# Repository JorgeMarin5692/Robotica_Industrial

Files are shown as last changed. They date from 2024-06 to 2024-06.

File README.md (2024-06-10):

# Proyecto Robotica 

Este repositorio GitHub contiene los documentos y archivos necesarios para construir un robot de 5 grados de libertad (5DOF). El robot está diseñado para ser una plataforma versátil para el aprendizaje y la experimentación en robótica. Se puede utilizar para una amplia gama de tareas, incluyendo:

- Manipulación de objetos: El robot puede agarrar y mover objetos de diferentes formas y tamaños.
- Brazo robótico: El robot se puede utilizar como un brazo robótico para realizar tareas más complejas.

# Diseño 3D
El inicio del proyecto de creación de un brazo robótico por parte de estudiantes estuvo marcado por la crucial etapa del diseño 3D, utilizando la herramienta Solidworks como piedra angular para el éxito del mismo. Solidworks, un software de CAD (Diseño Asistido por Computadora) de gran potencia y versatilidad, permitió a los estudiantes plasmar sus ideas en modelos digitales precisos y detallados.

Esta etapa inicial fue de vital importancia, ya que sentó las bases para el posterior desarrollo físico del brazo robótico. Mediante Solidworks, los estudiantes pudieron crear representaciones virtuales de cada componente del brazo, desde las articulaciones y eslabones hasta los elementos de sujeción y control. Esto permitió a los involucrados en el proyecto visualizar con claridad la forma, dimensiones y relaciones entre las distintas partes del robot, facilitando así la toma de decisiones técnicas acertadas.

La precisión y el detalle de los modelos 3D generados en Solidworks no solo fueron útiles para la conceptualización del diseño, sino que también sirvieron como insumo fundamental para la etapa de manufactura. Los modelos digitales pudieron exportarse en formatos compatibles con las impresoras 3D, permitiendo la fabricación precisa y eficiente de cada componente del brazo robótico. De esta manera, las ideas de los estudiantes se materializaron en piezas físicas tangibles.

WhatsApp Image 2024-06-09 at 6 02 45 PM

# Adquisición de los componentes

Tras la meticulosa etapa de diseño 3D, llegó el momento de materializar el brazo robótico mediante la adquisición de los componentes necesarios para su construcción. Con base en las especificaciones técnicas definidas durante la fase de diseño, se procedió a la compra de los siguientes elementos:

Servomotores: Se seleccionaron dos tipos de servomotores para el proyecto: los MG996R y los SG90. Los MG996R, con su mayor torque y precisión, se destinaron a las articulaciones principales del brazo, mientras que los SG90, más económicos y livianos, se emplearon en las articulaciones secundarias.

Placa Arduino Uno: Esta placa microcontroladora, reconocida por su facilidad de uso y versatilidad, se convirtió en el cerebro del brazo robótico. Su capacidad de procesamiento y comunicación con los periféricos la convirtió en la opción ideal para controlar los movimientos del brazo y la interacción con los sensores.

Placa PCA9685: Para ampliar la capacidad de control de servomotores del Arduino Uno, se incorporó la placa PCA9685. Esta placa de expansión permitió conectar y controlar hasta 16 servomotores adicionales, lo que resultó fundamental para la compleja estructura articulada del brazo robótico.

Jumpers: Estos cables de conexión flexibles sirvieron para establecer las conexiones eléctricas entre la placa Arduino Uno, la placa PCA9685, los servomotores y los sensores. Su practicidad y facilidad de uso agilizaron el proceso de ensamblaje y configuración del sistema.

Fuente de voltaje: Para alimentar de forma estable a todos los componentes electrónicos del brazo robótico, se adquirió una fuente de voltaje de corriente continua con la capacidad y el voltaje adecuados. Esto garantizó el correcto funcionamiento de los servomotores, la placa Arduino Uno y la placa PCA9685.

Filamento PLA: Para la impresión 3D de las piezas diseñadas en Solidworks, se utilizó filamento PLA (ácido poliláctico). Este material biodegradable, de alta calidad y fácil impresión, fue la elección ideal para la fabricación de las estructuras livianas y resistentes del brazo robótico.

Tornillería: Para asegurar la fijación precisa y robusta de las piezas impresas en 3D y los componentes electrónicos, se adquirió un surtido de tornillos, tuercas y arandelas de diferentes tamaños y materiales. La selección cuidadosa de la tornillería garantizó la estabilidad y durabilidad del brazo robótico.

WhatsApp Image 2024-06-09 at 6 00 48 PM

# Entorno de simulación 

Tras haber desarrollado el brazo robótico físico y su sistema de control mediante programación automática, el siguiente paso crucial en el proyecto es la creación de un entorno de simulación virtual. Este entorno permitirá probar, validar y optimizar el funcionamiento del brazo robótico en un ambiente controlado antes de su implementación en el mundo real.

Para la creación del entorno de simulación, se utilizará la combinación de dos potentes herramientas:

- ROS2 (Robot Operating System 2): Un marco de software de código abierto ampliamente utilizado en robótica para la comunicación entre diferentes nodos y la ejecución de tareas de forma distribuida.

- MoveIt: Un conjunto de herramientas de software para la planificación de movimiento y la manipulación robótica, integrado en el ecosistema ROS2. MoveIt proporciona algoritmos avanzados para generar trayectorias seguras y eficientes para el brazo robótico, considerando las limitaciones físicas y las restricciones del entorno.

Pasos para la creación del entorno de simulación:

- Instalación de ROS2 y MoveIt: Se instalará ROS2 y MoveIt en el sistema Ubuntu siguiendo las instrucciones oficiales de instalación.

- Modelado del brazo robótico: Se creará un modelo 3D preciso del brazo robótico utilizando herramientas de modelado 3D como es Solidworks. El modelo debe incluir todas las articulaciones, dimensiones y propiedades físicas del brazo real.

- Integración del modelo en ROS2: Se integrará el modelo 3D del brazo robótico en el entorno de simulación ROS2 utilizando herramientas como RViz. Esto permitirá visualizar el brazo robótico en el entorno virtual y controlar sus movimientos mediante comandos ROS2.

- Configuración de MoveIt: Se configurará MoveIt para que funcione con el modelo del brazo robótico y el entorno de simulación. Esto implica definir las articulaciones, las propiedades físicas y los límites de movimiento del brazo, así como los parámetros de planificación de movimiento.

- Pruebas y validación: Se realizarán pruebas exhaustivas para verificar el correcto funcionamiento del entorno de simulación, la precisión del modelo del brazo robótico y la eficacia de los algoritmos de planificación de movimiento de MoveIt.

Beneficios del entorno de simulación:

- Validación de movimientos: El entorno de simulación permite probar y validar diferentes movimientos del brazo robótico sin necesidad de riesgo para el hardware real.

- Optimización de la programación: Se puede optimizar la programación del brazo robótico en el entorno de simulación antes de implementarla en el sistema físico.

- Detección de errores: El entorno de simulación facilita la detección de errores en la programación o en el modelo del brazo robótico antes de que causen problemas en el sistema real.

- Entrenamiento de algoritmos: El entorno de simulación puede utilizarse para entrenar y optimizar algoritmos de control o de planificación de movimiento para el brazo robótico.

- Pruebas en diferentes entornos: Se pueden realizar pruebas en diferentes entornos virtuales para evaluar el comportamiento del brazo robótico en diversas situaciones y condiciones.
  
WhatsApp Image 2024-06-09 at 7 09 23 PM

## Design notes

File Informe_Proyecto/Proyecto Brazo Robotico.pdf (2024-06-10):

# Brazo robotico ´

### Mateo Mendoza Vera mmendoz80080@universidadean.edu.co Jorge Andres Mar ´ ín jmarina75692@universidadean.edu.co Guillermo Esteban Marquez ´ gmarque75991@universidadean.edu.co Camilo Andres Avilan Payares cavilan11027@universidadean.edu.co

### Universidad EAN Facultad de Ingeniería

Diseno Mecatr ˜ | onica ´

### Bogotá

2024

1

## Resumen

Este documento se enfoca en la creacion de un brazo rob ´ | otico articulado, ´
disenado principalmente para exposiciones acad ˜ | emicas, en este caso para la ´
unidad de estudio Diseno mecatronico. Aborda los problemas de eficiencia y ˜ seguridad presentes en disenos anteriores, con el objetivo de mejorar estos as- ˜ pectos. La metodología implementada abarca desde el diseno inicial hasta el ˜ ensamblaje final, haciendo uso de Trello como herramienta para el seguimiento
del proyecto. Se destaca por obtener como resultado un brazo robotico r ´ | api- ´
do, confiable y seguro, adecuado para demostraciones academicas a peque ´ | nã
escala.

## Introducción

En este proyecto se desarrolla un brazo robotico de 4 grados de libertad ´ (DoF) utilizando servomotores, con un diseno tridimensional elaborado en So- ˜ lidWorks y controlado mediante una tarjeta Arduino. La programacion del bra- ´ zo robotico se realiza en ROS2 (Robot Operating System 2), un marco de trabajo ´
robusto y flexible que permite la simulacion y control de sistemas rob ´ | oticos. ´

## Objetivo General

Disenar, construir y programar un brazo rob ˜ | otico que sea capaz de realizar ´
tareas de manipulacion y agarre de objetos en un entorno simulado y real. ´ Para lograr esto, se emplean herramientas de diseno asistido por computadora ˜ (CAD) como solidworks para modelar cada componente del brazo, servomotores para el movimiento preciso de las articulaciones, y una tarjeta Arduino para
el control y la comunicacion con el software de ROS2. La simulaci ´ | on en ROS2 ´
permite probar y validar los algoritmos de control y las trayectorias del brazo antes de implementarlos en el hardware real. Esta metodología reduce el riesgo
de errores y danos en el prototipo f ˜ | ísico, ademas de facilitar la optimizaci ´ | on de ´
los parametros del sistema. ´

## Objetivos Específicos

Crear un modelo detallado del brazo robotico en SolidWorks, incluyendo ´ eslabones, juntas y el mecanismo de la pinza.

Desarrollar y programar los algoritmos de cinematica directa e inversa ´ para controlar el movimiento del brazo.

Implementar el modelo del brazo en un entorno de simulacion utilizando ´ ROS2, y probar las capacidades de manipulacion y agarre. ´

2

Imprimir en 3D las piezas del brazo robotico, ensamblar el hardware y ´ conectar los servomotores a la tarjeta Arduino.

Programar la tarjeta Arduino para recibir comandos desde ROS2 y controlar los servomotores, y realizar pruebas funcionales para asegurar que el brazo opere segun lo previsto. ´

## 1. Estado del Arte

Los brazos roboticos, son dispositivos programables que imitan el movi- ´ miento y la funcion de un brazo humano. Se componen de una serie de eslabo- ´ nes conectados por articulaciones que les permiten realizar una amplia gama de movimientos, incluyendo:

Flexion´ /extension: Movimiento de un eslab ´ | on hacia adentro o hacia afuera ´
de una articulacion. ´
Abduccion´ /aduccion: Movimiento de un eslab ´ | on alej ´ | andose o acerc ´ | ando- ´
se al cuerpo del robot.
Rotacion: Movimiento de un eslab ´ | on alrededor de su eje longitudinal. ´
Los brazos roboticos son muy vers ´ | atiles en cuanto a sus funciones y las ´
aplicaciones que este puede realizar. En muchas empresas implementan estos
brazos roboticos tambi ´ | en por la precisi ´ | on que pueden llegar a tener en ciertas ´
tareas; aquí se presentan algunas aplicaciones de los brazos roboticos: ´

Manufactura: Puede ser el ensamblaje de productos, soldadura, pintura, manipulacion de materiales. ´

Logística: Desde el almacenamiento y recuperacion de productos, empa- ´ quetado, paletizado.

Medicina: Cirugía robotica, rehabilitaci ´ | on f ´ ísica, asistencia a personas con
discapacidades.

Agricultura: Cosecha de frutas y verduras, ordeno de vacas, control de ˜ plagas.

Exploracion espacial: Mantenimiento de sat ´ | elites, exploraci ´ | on de plane- ´
tas, recoleccion de muestras. ´

### 1.1. Componentes de un brazo robótico

Los principales componentes de un brazo robotico convencional son: ´

Eslabones: Segmentos rígidos que forman la estructura del brazo.

Articulaciones: Uniones entre eslabones que permiten el movimiento.

3

Actuadores: Motores que proporcionan la fuerza para mover las articulaciones.

Sensores: Dispositivos que recopilan informacion sobre el entorno del ´ brazo.

Controlador: Un sistema informatico que procesa las se ´ | nales de los sen- ˜
sores y envía comandos a los actuadores.

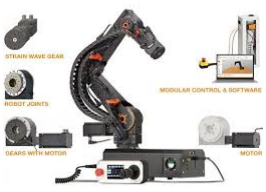
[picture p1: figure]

Figura 1: Componentes de un Brazo Robotico

Aunque segun la complejidad del brazo rob ´ | | | otico se podr ´ | ían necesitar otros
materiales o con otro tipo de características específicas.

### 1.2. Tipos de brazos robóticos

Existen gran variedad de brazos roboticos seg ´ | un sus caracter ´ | ísticas, clasi-
ficados segun su dise ´ | no, cinem ˜ | atica y aplicaci ´ | on. Algunos de los tipos m ´ | as´
comunes son:
Brazos roboticos articulados: El tipo m ´ | as com ´ | un, con una serie de eslabo- ´
nes conectados por articulaciones rotativas.

Brazos roboticos cartesianos: Se mueven en tres direcciones ortogonales ´ (X, Y, Z) mediante actuadores lineales.

Brazos roboticos de brazo scara: Un tipo de brazo cartesiano con mayor ´ alcance y flexibilidad.

Brazos roboticos colaborativos (cobots): Dise ´ | nados para trabajar de forma ˜
segura junto a humanos. (Blog, s/f)

4

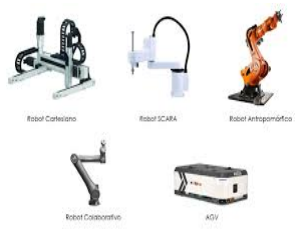
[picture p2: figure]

Figura 2: Tipos de brazos roboticos

### 1.3. Evolución de los brazos Robóticos

Aquí se exponen algunas de las tecnologías clave que estan impulsando el ´ desarrollo de brazos roboticos: ´

Inteligencia artificial (IA): La IA se utiliza para mejorar la precision, la ´ destreza y la autonomía de los brazos roboticos. ´

Robotica sensorial: Los sensores cada vez m ´ | as sofisticados proporcionan ´
a los brazos roboticos una mejor comprensi ´ | on de su entorno. ´
Materiales avanzados: Los materiales mas ligeros y resistentes est ´ | an per- ´
mitiendo construir brazos roboticos m ´ | as eficientes y duraderos. ´
Impresion 3D: La impresi ´ | on 3D est ´ | a facilitando la creaci ´ | on de brazos ´
roboticos personalizados y complejos. ´

### 1.4. Aplicaciones futuras de los brazos robóticos

Se espera que los brazos roboticos tengan un impacto cada vez mayor en ´
nuestras vidas en los proximos a ´ | nos. Algunas de las aplicaciones potenciales ˜
incluyen:
Cuidado en el hogar: Los brazos roboticos podr ´ | ían ayudar a las personas
mayores y discapacitadas con tareas como cocinar, vestirse y banarse. ˜
Educacion: Los brazos rob ´ | oticos podr ´ | | ían utilizarse para ensenar a los ˜
estudiantes sobre robotica, ingenier ´ | | ía y otras materias.
Entretenimiento: Los brazos roboticos podr ´ | ían utilizarse para crear expe-
riencias de entretenimiento mas inmersivas. ´

5

Construccion: Los brazos rob ´ | oticos podr ´ | ían utilizarse para construir es-
tructuras mas seguras y eficientes. ´

### 1.5. Cinematica

(Inversa, s/f,pg 4. Estudia el movimiento del robot con respecto a un sistema de referencia sin considerar las fuerzas que intervienen. Estudia, ademas, las ´ relaciones entre las velocidades del movimiento de las articulaciones y las del extremo.)

### 1.5.1. Cinematica Inversa

(Inversa, s/f, pg 5. Consiste en determinar la posicion y orientaci ´ | on del ´
extremo final del robot, con respecto a un sistema de referencia, conocidos
los valores de las articulaciones (angulos) y los par ´ | ametros geom ´ | etricos de los ´
elementos del robot.)

### 1.5.2. Cinematica directa

(Inversa, s/f, pg 5. Consiste en determinar la posicion y orientaci ´ | on del ´
extremo final del robot, con respecto a un sistema de referencia, conocidos
los valores de las articulaciones (angulos) y los par ´ | ametros geom ´ | etricos de los ´
elementos del robot.)

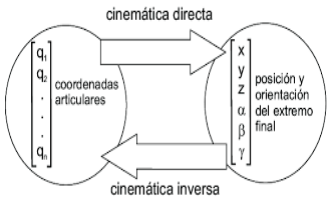
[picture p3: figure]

Figura 3: Comparacion cinematica inversa y directa

### 1.6. ROS2

O Robot Operating System 2, es la version m ´ as reciente y avanzada del ´ Sistema Operativo de Robots (ROS). Es una plataforma de desarrollo de codigo ´
abierto disenada para facilitar la creaci ˜ | on y operaci ´ | on de sistemas rob ´ | oticos ´
complejos. A diferencia de su predecesor, ROS, ROS2 esta dise ´ | nado para ser ˜

6

mas escalable, modular, robusto y adecuado para una variedad m ´ | as amplia de ´
aplicaciones y entornos.

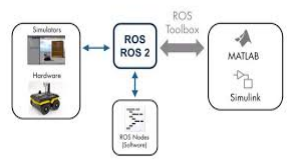
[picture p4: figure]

Figura 4: Apliccaciones ROS2

## 2. Metodología

Para el desarrollo de un brazo robotico se toma el siguiente procedimiento ´ general, aunque este procedimiento tendra que dividirse en etapas: ´

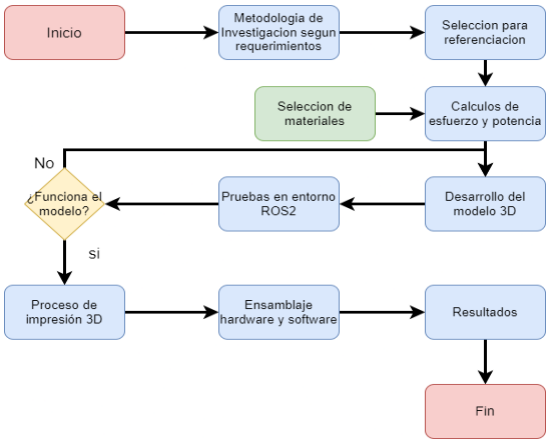
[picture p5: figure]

Figura 5: Ciclo de metodologia

7

A partir del estado del arte se pudo obtener un marco referencial respecto a proyectos con características similares tanto en el software y el hardware. Para
este caso, el tipo de brazo robotico a realizar es un brazo rob ´ | otico articulado el ´
cual es rapido, confiable y seguro; a una escala peque ´ | na, ideal para exposici ˜ | on´
en terminos acad ´ | emicos. La estructura, es decir, el hardware, est ´ | a basado en ´
este video: ([@FABRIcreator]., 2024). Para terminos de seguimiento de avances ´ se utiliza la plataforma de trello para buscar eficiencia en el proceso de cada uno de los participantes; este proyecto se divide en tres etapas principales: Diseno, ˜ definicion de presupuesto y ensamble ´

### 2.1. Dise ño

Teniendo en primera instancia el diseno se procede a hacer c ˜ | alculos genera- ´
les de los eslabones y el ensamble en general para así tener una idea de variables a tener en cuenta como torque necesario de los servomotores, esfuerzo, entre otras para asi hacer la respectiva seleccion de materiales. Para hacer calculos generales se necesita una densidad especifica para determinar la masa por cada cm3, por esto se acude a la siguiente tabla tomada de (Fonseca, s/f, p.26).

Cuadro 1: Comparacion de materiales ´
Características / Material Aluminio | Acero | Polímeros (PLA) Titanio
Densidad | 7 | 5 | 9 | 3
Transformacion | 8 | 8 | 3 | 3 ´
Acceso | 7 | 7 | 7 | 2
Restricciones intrínsecas | 7 | 8 | 5 | 9
Ensamblaje | 8 | 6 | 6 | 7
Resistencia mecanica | 7 | 8 | 6 | 10 ´
Compactibilidad | 5 | 2 | 3 | 10
Precio | 6 | 6 | 5 | 1
Total | 55 | 50 | 51 | 45
Se toma la decision de elegir la secci ´ | on de pol ´ | ímeros, específicamente el
PLA (Poliacido L ´ | actico), ya que como su objetivo es demostrarse en ´ | ambitos ´
academicos, su precio es el mas ascequible, esto sin desmeritar las propiedades ´ y ventajas que ofrece este material. Este material cuenta con una densidad de 1,24 g/cm3. Por consiguiente es necesario un procedimiento grafico para hacer la resolucion de calculos, es por eso que se disena un diagrama de cuerpo libre ˜ tentativo para asi tener una guia procedimental A continuacion se presenta una tabla con cada una de las piezas que componen al brazo robotico y sus caracteristicas para terminos de calculos.
Ahora se procede a hacer los calculos generales

8

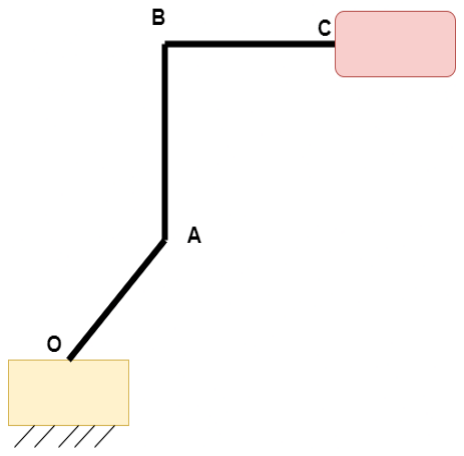
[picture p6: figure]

Figura 6: Diagrama de cuerpo Libre

Cuadro 2: Pesos y medidas de los componentes del brazo robotico ´
Componente | Peso | Medida
Servomotor MG996R | 55 gramos | -
Servomotor SG90 | 9 gramos | -
Seccion OA | 85 gramos | 4,05 cm ´
Seccion AB | 68,3 gramos | 12,0 cm ´
Seccion BC | 62,2 gramos | 9 cm ´
Sistema Garra | 32 gramos | 6,3 cm

### 2.1.1. Cálculos

Parámetros

L1 = 0,0405 m, | m1 = 0,855 kg | (1)
L2 = 0,12 m, | m2 = 0,682 kg | (2)
L3 = 0,09 m, | m3 = 0,62 kg | (3)
L4 = 0,063 m, | m4 = 0,57 kg | (4)
Carga tentativa = 0,5 kg | | (5)

Peso de cada segmento

Fg1 = 0,855 kg · 9,81 m/s | 2 = 8,38355 N | (6)
Fg2 = 0,682 kg · 9,81 m/s | 2 = 6,68842 N | (7)
Fg3 = 0,62 kg · 9,81 m/s | 2 = 6,0822 N | (8)
Fg4 = 0,57 kg · 9,81 m/s | 2 = 5,5917 N | (9)
Fc = 0,5 kg · 9,81 m/s | 2 = 4,905 N | (10)

9

Distancia desde articulación a centro de masa: Se supone las articulaciones como barras, por lo tanto, su centro de masa va a ser la mitad de su medida

dcm1 =

L1
2
= 0,02025 m | (11)

dcm2 =

L2
2
= 0,06 m | (12)

dcm3 =

L3
2
= 0,045 m | (13)

dcm4 =

L4
2
= 0,0315 m | (14)

Calculo de momento para cada articulacion

Articulacion 4 (debido al segmento 4 y la carga) ´

M4 = Fg4 · dcm4 = 5,5917 · 0,0315 = 0,17614905 Nm

Mc = Fc

- L4 = 4,905 · 0,063 = 0,309015 Nm

Mtotal4 = 0,17614905 + 0,309015 = 0,48516405 Nm

Articulacion 3 (debido al segmento 3, segmento 4 y la carga) ´

M3 = Fg3 · dcm3
= 6,0822 · 0,045
= 0,273699 Nm

Mtotal3 = M3 + (Mtotal4 + Fg4 · L3 + Fc

- (L3 + L4))
= 0,273699 + (0,48516405 + 5,5917 · 0,09 + 4,905 · (0,09 + 0,063)) = 0,273699 + (0,48516405 + 0,503253 + 0,750165)
= 0,273699 + 1,73858205
= 2,01228105 Nm

Articulacion 2 (debido al segmento 2, segmento 3, segmento 4 y la carga) ´

M2 = Fg2 · dcm2
= 6,68842 · 0,06
= 0,4013052 Nm

10

Mtotal2 = M2 + (Mtotal3 + Fg3 · L2 + Fg4 · (L2 + L3) + Fc

- (L2 + L3 + L4))
= 0,4013052 + (2,01228105 + 6,0822 · 0,12 + 5,5917 · (0,12 + 0,09) + 4,905 · (0,12 + 0,09 + 0,063))
= 0,4013052 + (2,01228105 + 0,729864 + 1,174257 + 1,339065) = 0,4013052 + 5,25546705
= 5,65677225 Nm

Articulacion 1 (debido al segmento 1, segmento 2, segmento 3, segmento ´ 4 y la carga)

M1 = Fg1 · dcm1
= 8,38355 · 0,02025
= 0,1697953875 Nm

Mtotal1 = M1 + (Mtotal2 + Fg2 · L1 + Fg3 · (L1 + L2) + Fg4 · (L1 + L2 + L3) + Fc

- (L1 + L2 + L3 + L4))
= 0,1697953875 + (5,65677225 + 6,68842 · 0,0405 + 6,0822 · (0,0405 + 0,12)
+ 5,5917 · (0,0405 + 0,12 + 0,09) + 4,905 · (0,0405 + 0,12 + 0,09 + 0,063))
= 0,1697953875 + (5,65677225 + 0,27087401 + 0,9762491 + 1,40017885 + 1,5374175) = 0,1697953875 + 9,84149171
= 10,0112871 Nm

Cinematica Directa y Inversa
Para calcular la cinematica directa, se utilizo el metodo de D-H(Denavit Hatenberg), para ver el movimiento del robot.
θj | dj | aj | αj
q1 | 40.38 | 0 | ◦ −90,0
q2 + 90◦ | 0 | 120 | 0,0 ◦
q3 | 115 | 0 | 90,0 ◦
q4 − 90◦ | 31.76 | 0 | 90,0 ◦
q5 | 0 | 0 | 0,0 ◦

Cuadro 3: Tabla de parametros de Denavit-Hartenberg ´

Gracias al programa Google Colab, y por medio de la libreria Robotic-Toolbox, se logro sacar los resultados tanto de la cinematica directa como aquellos abrebocas de la cinematica inversa, los cuales mas adelante se veran por medio de los metodos de Newthon Raphson (Jacobiano) Para lo siguiente se definieron los parametros cinematicos a trabajar por medio de tres ecuaciones de coordenadas del brazo (X,Y,Z).

11

0 | 1 | 0 | 31.76
-1 | 0 | 0 | 115
0 | 0 | 1 | -79.62
0 | 0 | 0 | 1

Cuadro 4: Matriz de Cinematica Directa ´

x = l1 cos(θ1)+l2 cos(θ1+θ2)+l3 cos(θ1+θ2+θ3)+l4 cos(θ1+θ2+θ3+θ4)+l5 cos(θ1+θ2+θ3+θ4+θ5) (15)

y = l1 sin(θ1)+l2 sin(θ1+θ2)+l3 sin(θ1+θ2+θ3)+l4 sin(θ1+θ2+θ3+θ4)+l5 sin(θ1+θ2+θ3+θ4+θ5) (16)

z = l1+l2 sin(θ2)+l3 sin(θ2+θ3)+l4 sin(θ2+θ3+θ4)+l5 sin(θ2+θ3+θ4+θ5)
(17)

Resultados
Los momentos calculados para cada articulacion son: ´
Articulacion 4: 0 ´ | ,4852 Nm
Articulacion 3: 2 ´ | ,0123 Nm
Articulacion 2: 5 ´ | ,6568 Nm
Articulacion 1: 10 ´ | ,0113 Nm

Es de aclarar que estos calculos da una idea del torque y de saber si es apropiado tener los servomotores que se postularon en un inicio, y por esto se supone que los motores MG996R y SG90 tienen la capacidad de torque.
Si bien en un principio el diseno para su respectiva impresi ˜ | on 3D de las ´
piezas que conforman el brazo robotico ya estaban listas, fue necesario realizar ´ el brazo a partir de las medidas de este mismos en solidworks, ya que para
la simulacion y obtenci ´ | on de planos para este software eran incompatibles los ´
archivos. Una vez listas las piezas y el ensamblaje se procede a hacer simula-
cion din ´ | amica en el software para la respectiva comparaci ´ | on con los c ´ | alculos ´
realizados anteriormente.
En el aspecto del software para el control del robot se disenõ un c ´ | odigo en ´
Python inicialmente para hacer la respectiva simulacion en ROS2 y as ´ | í verificar
los resultados de dicha simulacion con las posibles fallas del sistema. Una vez ´
teniendo todo el aspecto de diseno listo se procede a la cotizaci ˜ | on de materiales ´
y la realizacion de un presupuesto tentativo. ´

12

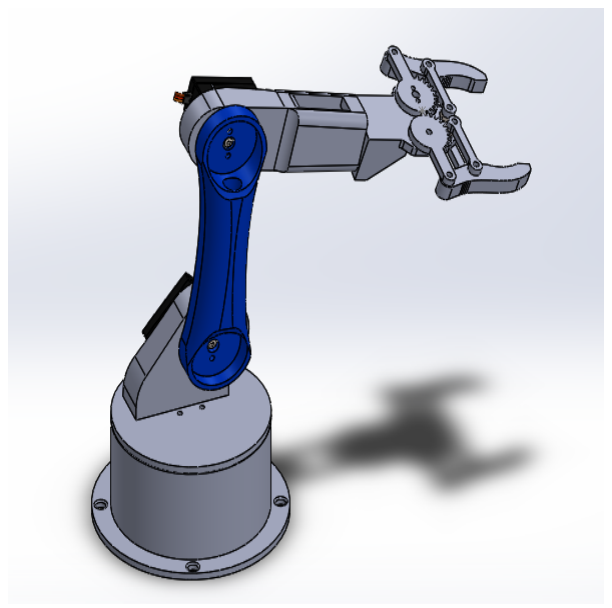
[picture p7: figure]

Figura 7: Modelo en solidworks

### 2.2. Presupuesto

Para hacer un respectivo presupuesto para la realizacion de un brazo rob ´ | oti- ´
co fue necesario revisar y analizar el estado del arte que conlleva este tipo de proyectos, incluyendo tambien un marco referencial, requisitos suministrados ´ por el tutor y algunas sugerencias de este mismo. Al hacer este proceso se pudieron implementar los siguientes materiales, a su vez se establece un posible presupuesto para implementar.

Cuadro 5: Materiales y Presupuesto
Materiales | | Cantidad | Precio Total
Filamento PLA | | 1 Kg | $80.000
Servomotor MG996R | | 2 | $60.000
Servomotor MG90S | | 1 | $18.000
Servomotor SG90 | | 1 | $13.000
Modulo PCA9685 | | 1 | $30.000
Arduino Mega | | 1 | $150.000
Tornillos m3 12mm | | 10 | $10.000
Tornillos m3 16mm | | 10 | $10.000
Miscelaneos | N ´ | /A | $20.000
| | Total: | $325.000

Es necesario tener en cuenta que los precios son tomados de internet en sitios como mercado libre, Amazon y google shopping; es por esto que, puede

13 ser que estos materiales comprados de manera física pueden variar su precio, probablemente sea menor su precio unitario.
Se tomaron los precios promedio del mercado, ya que en internet aparecen artículos con mayor y menor precio. Es por esto que se considera que el presupuesto necesario para el debido desarrollo de este proyecto sea de COP $350.000.

### 2.3. Ensamble

En esta parte del proceso es preciso indicar que se divide en dos partes, la parte de conexiones electronicas, y la parte estructural del brazo robotico. Para la parte de conexiones electronicas fue de gran ayuda el uso del modulo PCA9685, ya que reduce las conexiones al arduino y asi se puede optimizar mejor el codigo. En este caso se utilizaron exclusivamente 5 servomotores.

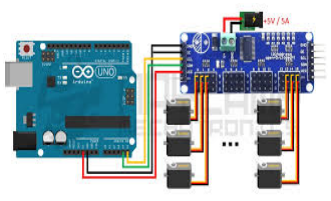
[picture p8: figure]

Figura 8: Conexiones del Brazo Robotico

Como ya se tenía el diseno, se procedi ˜ | o a someter el dise ´ | no a impresi ˜ | on´
3D para la obtencion de los eslabones y ´ | /o estructura del brazo robotico, el cual ´
con la impresora que se uso tuvo un tiempo aproximado de 18 horas para la ´ obtencion de las piezas. Teniendo las piezas y todos los elementos necesarios ´ para su construccion se procedio a ensamblar. ´
Despues se realizaron dos codigos los cuales se puede controlar el brazo de forma manual y automatica, estos se pueden encontrar en el repositorio GitHub.

## Implementación

Una vez teniendo el hardware, fue necesario acoplar el software al sistema. El software, se hizo un codigo en arduino para el respectivo control de posicion´

14

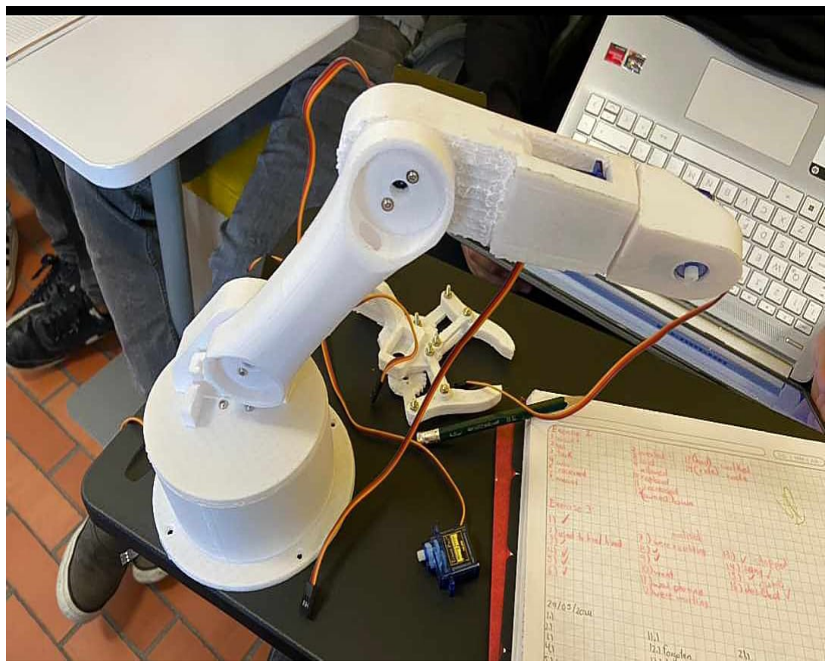
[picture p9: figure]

Figura 9: Proceso de ensamblaje

del brazo robotico, luego se sometio a pruebas tales como de cargue de objetos, ´ coincidencia de posicion, pruebas de velicidad, entre otros. Fue necesario ajustar varios parametros despues de exhaustivas pruebas, ya que en el control del brazo robotico hubieron percances. ´

## Resultados

Al final de hacer todo el proceso de cinematica y sus respectivas correcciones en el codigo de control, se logro controlar efectivamente el brazo robotico, ´ teniendo una buena respuesta y suavizada en cada movimiento de las articulaciones que contiene este, tambien se logro reducir el ruido por friccion de ´ cada motor, ya que en este sistema no se implemento sistema de transmicion de ´ potencia alguna, los servomotores van directamente acoplados a las articulaciones, pero ocurria una friccion, fue necesario acoplar arandelas para reducir su friccion. Tambien se corrigio cuestiones de diseno de algunas articulacio- ˜ nes, especialmente la seccion 4, ya que no quedaba bien incrustada y generaba oscilaciones. En cuestiones de conexiones electricas fue necesario acoplar una bateria de mayor amperaje para los 5 servomotores, pero manteniendo el voltaje de 5v+. Aqui se puede observar una prueba de ello:

15

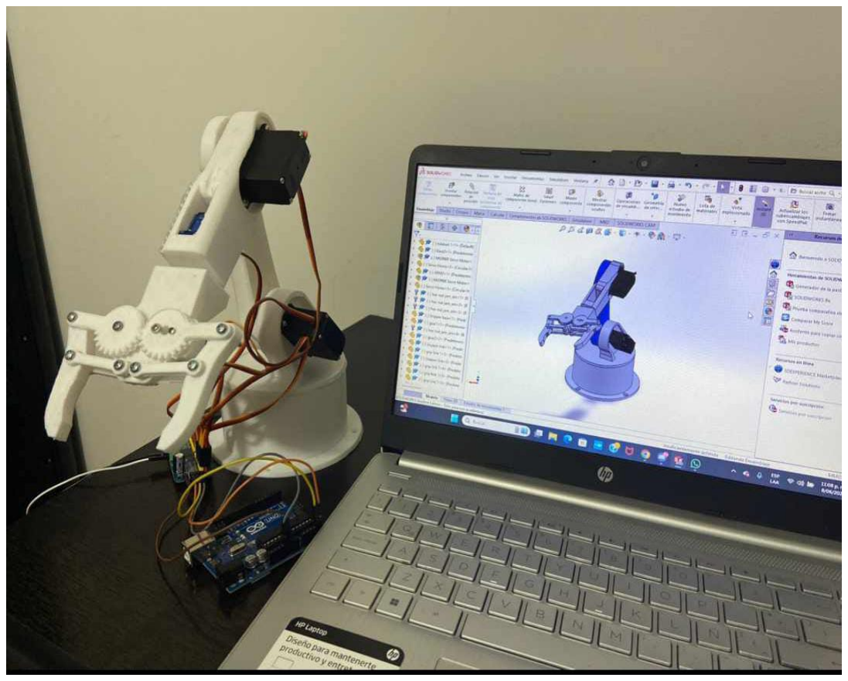
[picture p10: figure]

Figura 10: Resultado de Brazo robootico ´

## Conlusiones

Hubieron varias complicaciones y fallas en el desarrollo y puesta a prueba del proyecto, principalmente en el diseno 3D y su respectiva simulacion, ˜ y en la parte de control.

Con este proyecto se evidencio la cobertura de forma extensa las ramas que estan inmersos los ingenieros mecatronicos (programacion, disenõ mecanico, control).

Se logro el objetivo inicial del proyecto que era dise ´ | nar y construir un ˜
brazo robotico articulado de 4 grados de libertad con un sistema de agarre ´ integrado.

Hay cuestiones por mejorar para futuros proyectos como un mejor analisis mecanico para iniciar pruebas reales y asi no someter a cualquier peligro a los componentes.

## Referencias

Creator, F. [@FABRIcreator]. (2024, abril 2). Brazo robotico con Arduino ´
- Robotic Arm - Guardar/Reproducir/Exportar/Importar Movimientos. Youtube. https://www.youtube.com/watch?v=1b1YxPmp97I

16

Fonseca, C. R. D. (s/f). DISENO DE UN BRAZO ROB ˜ | OTICO ARTICULA- ´
DO. Recuperado de
https://repository.usta.edu.co/bitstream/handle/11634/50508/PROYECTO

Blog, S. (s/f). Tipos de brazos roboticos: mostramos sus aplicaciones in- ´ dustriales. Structuralia.com. Recuperado el 9 de junio de 2024, de https://blog.structuralia.com/tipos-de-brazos-roboticos

ChatGPT. (s/f). Chatgpt.com. Recuperado el 9 de junio de 2024, de https://chatgpt.com/c/f5244bcc-f142-42ad-9e86-fb37764fb340

Curso de ROS2 para principiantes. (2024, febrero 16). Curso de Instalador. https://cursodeinstalador.com/curso-de-ros2-para-principiantes/

Gemini: Chatea para potenciar tus ideas. (s/f). Gemini. Recuperado el 9 de junio de 2024, de https://gemini.google.com/app/dda1587cd7588981

Inversa, C. (s/f). Fundamentos de Robotica. Uta.cl. Recuperado el 9 de ´
junio de 2024, de
http://www.eudim.uta.cl/rmendozag/courses/fundamentosrobotica/lectures/cinematicainversa.pd f

Vier, P. (s/f). ¿Que son las articulaciones de un robot? Coldjet.com. Recuperado ´
el 9 de junio de 2024, de
https://blog-mx.coldjet.com/que-son-las-articulaciones-de-un-robot

## Anexos

CODIGO DE CINEMATICA DIRECTA E INVERSA

https://colab.research.google.com/drive/1DMUY4OwlwX3rFa-4xcwDKS5D9bfk0bg9?usp=sharing

Github

https://github.com/JorgeMarin5692/RoboticaIndustrial/tree/master

17

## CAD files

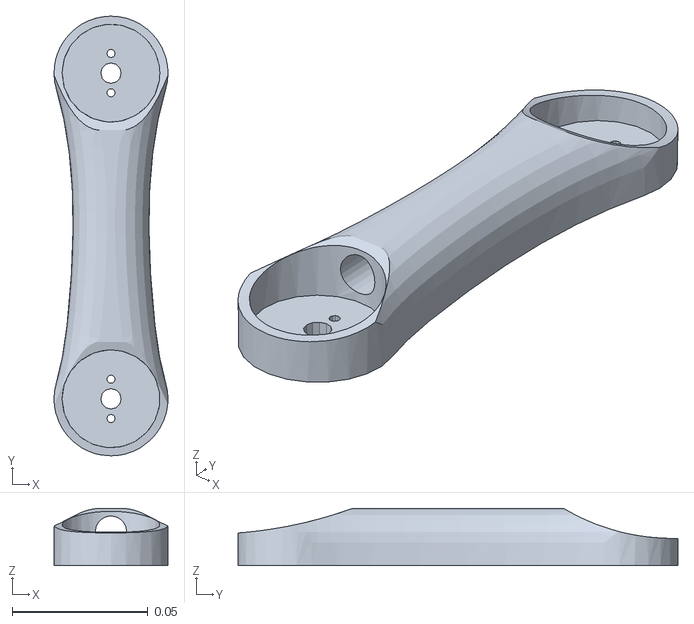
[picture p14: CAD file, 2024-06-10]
BrazoparaURDF/meshes/Eslabon_1_link.STL
0.042 x 0.162 x 0.021

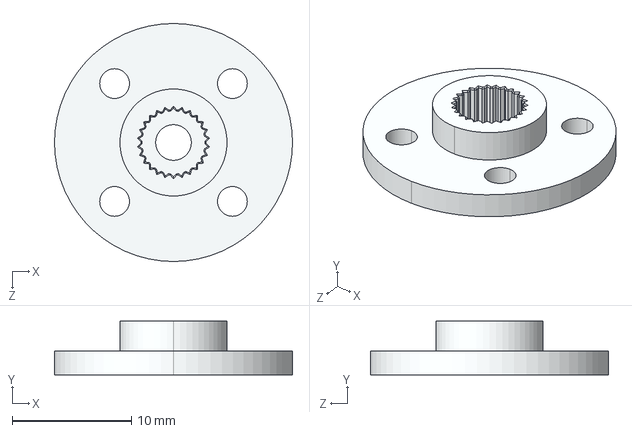
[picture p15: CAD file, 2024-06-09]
Disenio 3D/Disco Servo/Servo disk/Servo disc.STEP
20.0 x 4.50 x 20.0 mm

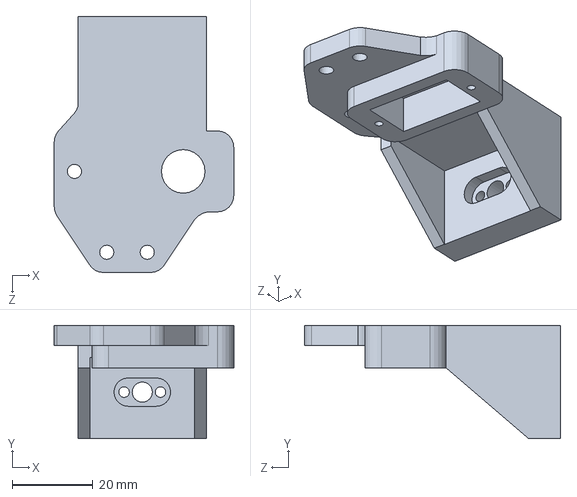
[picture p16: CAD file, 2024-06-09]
Disenio 3D/Gripper base.SLDPRT
44.4 x 28.0 x 63.3 mm

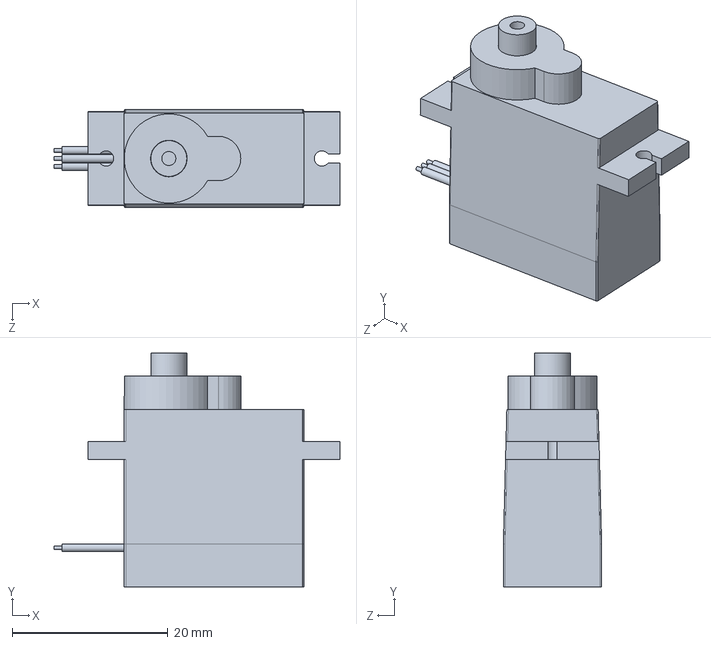
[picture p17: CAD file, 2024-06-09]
Disenio 3D/Servo SG90/Tower+Pro+9g+Micro+Servo+SG90.SLDPRT
36.7 x 30.0 x 12.6 mm

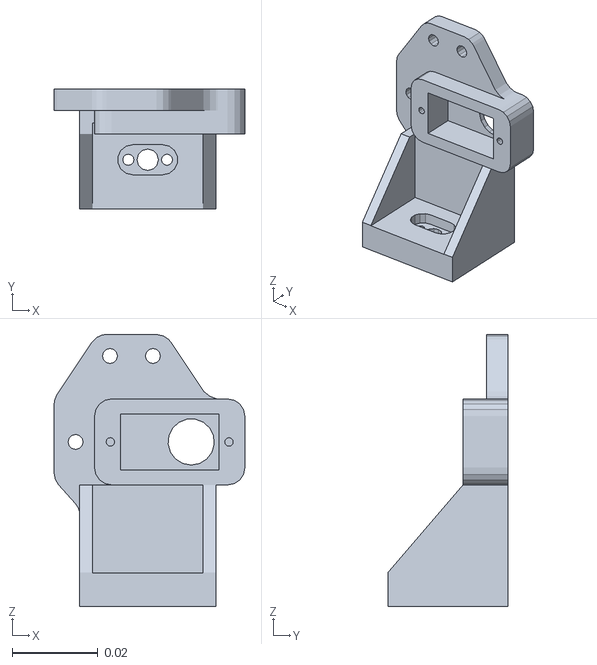
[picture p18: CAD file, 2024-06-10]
BrazoparaURDF/meshes/Eslabon_3_link.STL
0.0444 x 0.028 x 0.0633

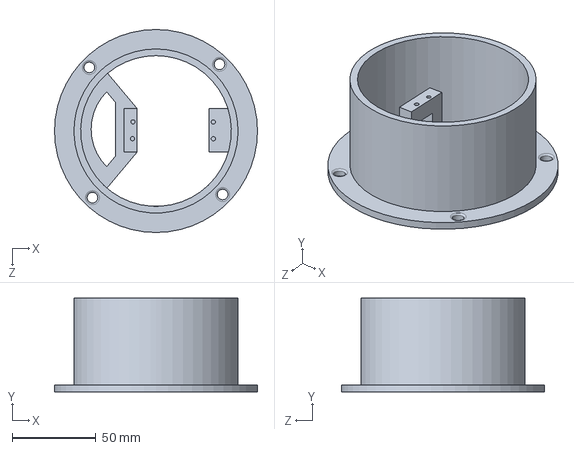
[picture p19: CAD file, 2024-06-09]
Disenio 3D/BaseFinal.SLDPRT
121.2 x 56.0 x 121.2 mm

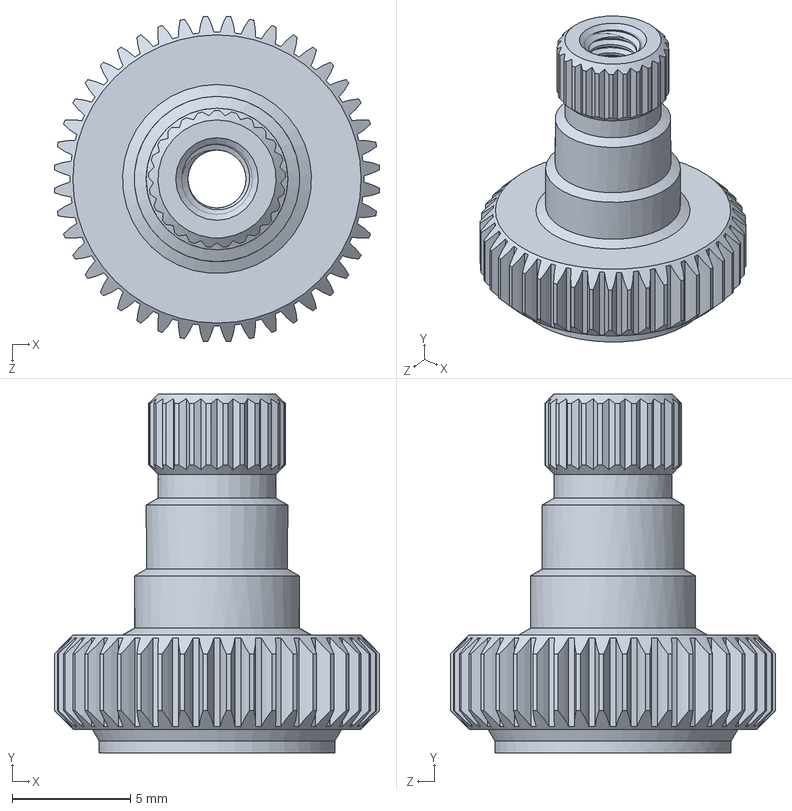
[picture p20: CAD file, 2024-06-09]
Disenio 3D/servoMG996R/MG996R Servo Motor/Output Shaft.SLDPRT
13.8 x 15.2 x 13.8 mm

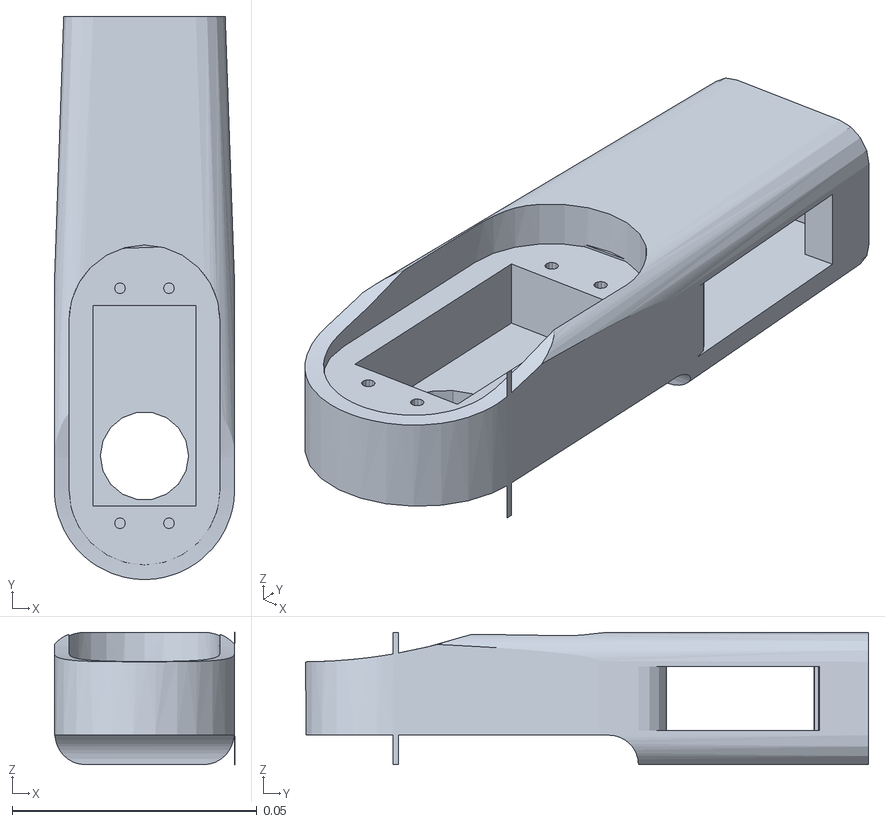
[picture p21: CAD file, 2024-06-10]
BrazoparaURDF/meshes/Eslabon_2_link.STL
0.0369 x 0.115 x 0.027

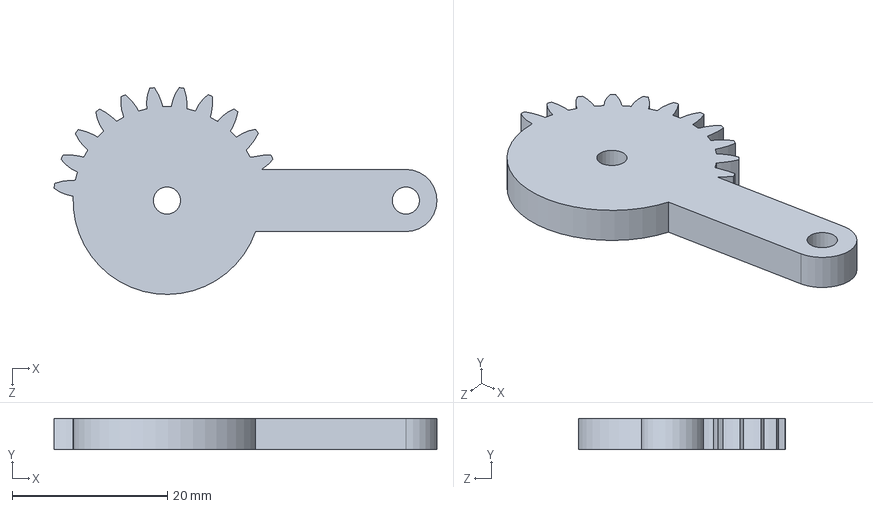
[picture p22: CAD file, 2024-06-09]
Disenio 3D/gear1.SLDPRT
49.3 x 4.00 x 26.6 mm

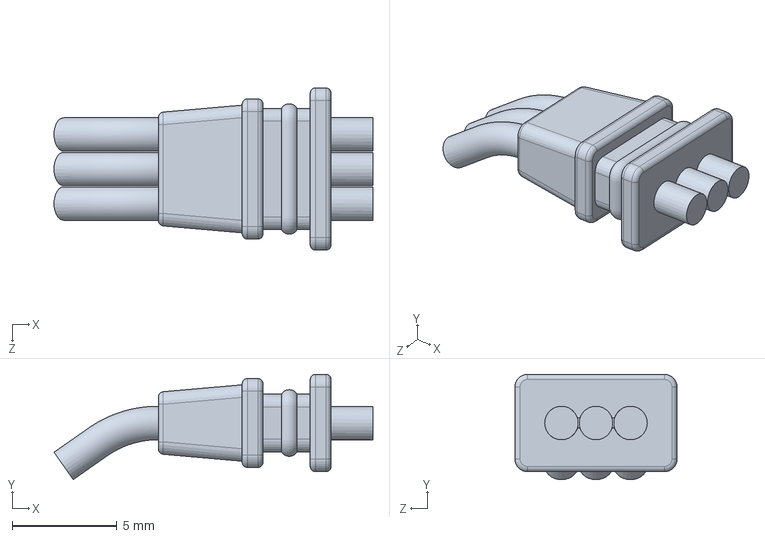
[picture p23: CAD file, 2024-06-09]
Disenio 3D/servoMG996R/MG996R Servo Motor/Rubber Wire Cable Sleeve.SLDPRT
15.2 x 5.03 x 7.75 mm

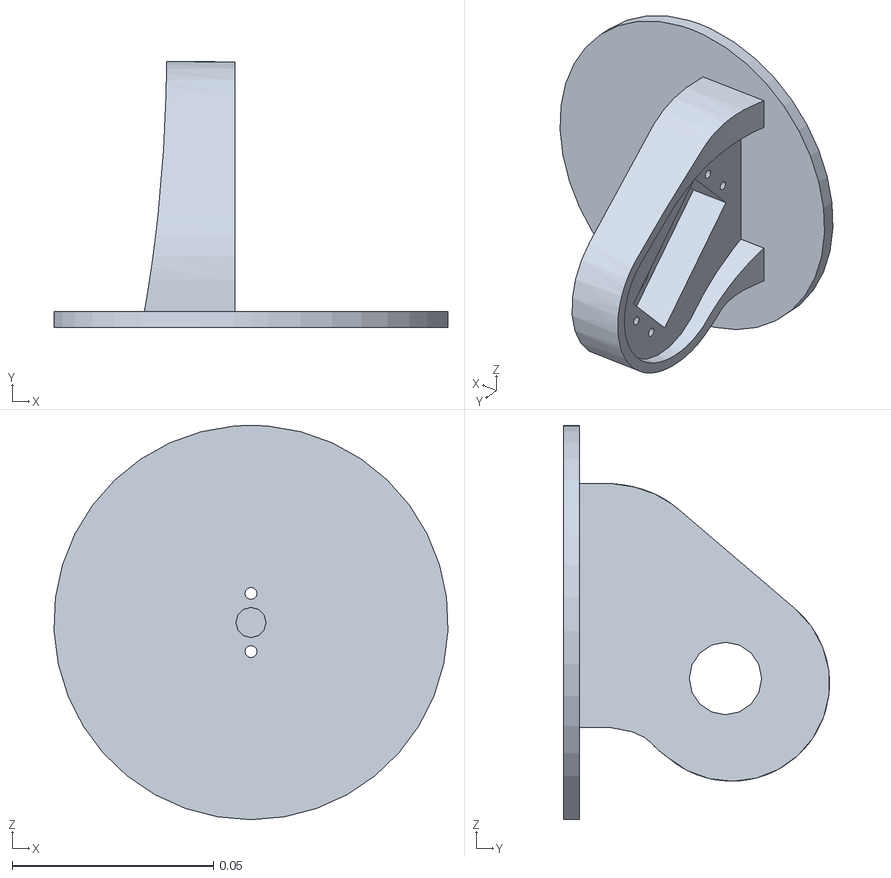
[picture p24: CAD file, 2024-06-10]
BrazoparaURDF/meshes/Base_2_link.STL
0.0979 x 0.0662 x 0.098

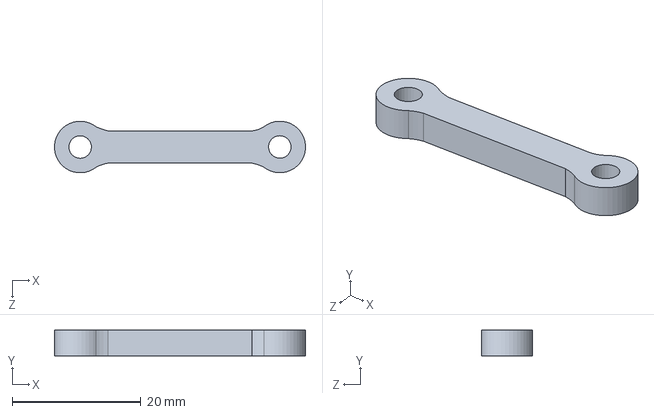
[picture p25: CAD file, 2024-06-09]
Disenio 3D/grip link 1.SLDPRT
39.0 x 4.00 x 8.00 mm

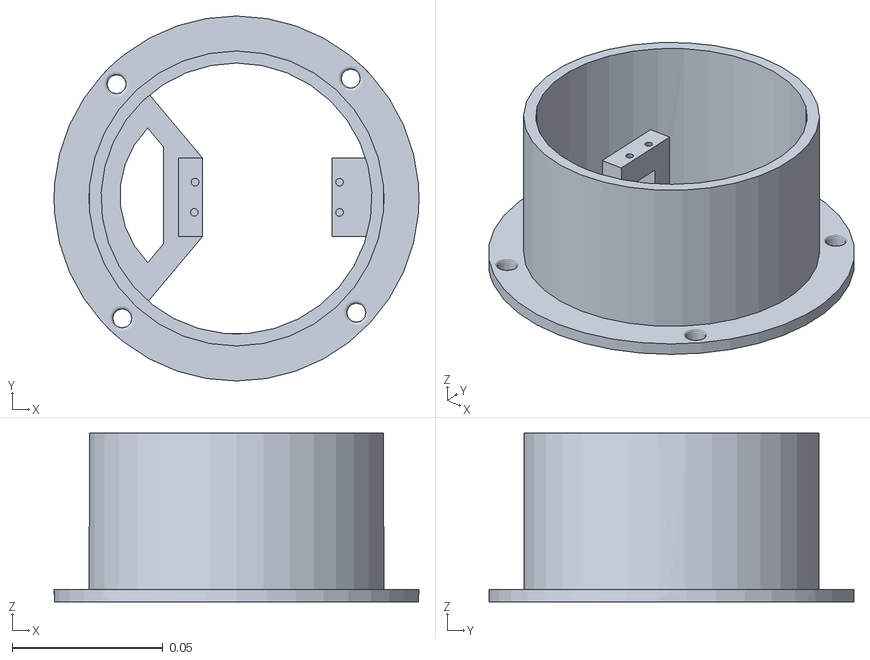
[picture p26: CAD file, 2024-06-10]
BrazoparaURDF/meshes/base_link.STL
0.121 x 0.121 x 0.056

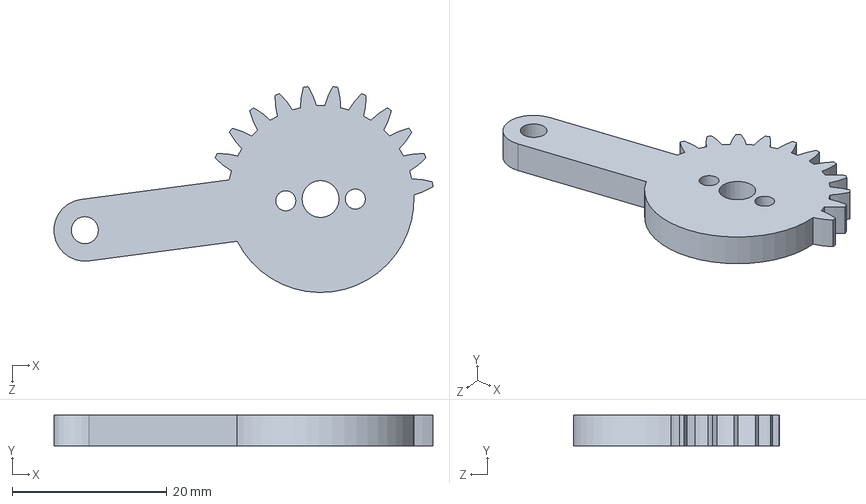
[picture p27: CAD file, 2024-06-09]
Disenio 3D/gear2.SLDPRT
49.0 x 4.00 x 26.6 mm

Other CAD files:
Disenio 3D/servoMG996R/MG996R Servo Motor/Servo Horns.SLDPRT
Disenio 3D/Base2.SLDPRT
Disenio 3D/servoMG996R/MG996R Servo Motor/Case.SLDPRT
Disenio 3D/eslabon 1.SLDPRT
Disenio 3D/ARM2.SLDPRT
Disenio 3D/Disco Servo/Servo disk/Servo disc.SLDPRT
Disenio 3D/Gripper link.SLDPRT
Disenio 3D/servoMG996R/MG996R Servo Motor/MG996R Servo Motor.x_t
Disenio 3D/servoMG996R/MG996R Servo Motor/Pan Head Cross Screw M1.6.SLDPRT
Disenio 3D/servoMG996R/MG996R Servo Motor/Pan Head Cross Screw M3.SLDPRT
Planos 2D/ARM2.SLDDRW
Planos 2D/Base2.SLDDRW
Planos 2D/BaseFinal.SLDDRW
Planos 2D/Gripper base.SLDDRW
Planos 2D/Gripper link.SLDDRW
Planos 2D/eslabon 1.SLDDRW
Planos 2D/gear1.SLDDRW
Planos 2D/gear2.SLDDRW
Planos 2D/grip link 1.SLDDRW

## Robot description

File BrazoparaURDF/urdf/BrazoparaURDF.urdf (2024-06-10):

<?xml version="1.0" encoding="utf-8"?>
<!-- This URDF was automatically created by SolidWorks to URDF Exporter! Originally created by Stephen Brawner (brawner@gmail.com) 
     Commit Version: 1.6.0-4-g7f85cfe  Build Version: 1.6.7995.38578
     For more information, please see http://wiki.ros.org/sw_urdf_exporter -->
<robot name="BrazoparaURDF">
  <link name="base_link">
    <inertial>
      <origin xyz="0.0026513 0.021626 -5.607E-05" rpy="0 0 0" />
      <mass value="0.1036" />
      <inertia ixx="0.00012888" ixy="-1.0446E-06" ixz="1.5043E-07" iyy="0.00021815" iyz="2.4556E-09" izz="0.00014888" />
    </inertial>
    <visual>
      <origin xyz="0 0 0" rpy="0 0 0" />
      <geometry>
        <mesh filename="package://BrazoparaURDF/meshes/base_link.STL" />
      </geometry>
      <material name="">
        <color rgba="0.79216 0.81961 0.93333 1" />
      </material>
    </visual>
    <collision>
      <origin xyz="0 0 0" rpy="0 0 0" />
      <geometry>
        <mesh filename="package://BrazoparaURDF/meshes/base_link.STL" />
      </geometry>
    </collision>
  </link>
  <link name="Base_2_link">
    <inertial>
      <origin xyz="-0.0066409 0.017974 -0.002134" rpy="0 0 0" />
      <mass value="0.068942" />
      <inertia ixx="6.1349E-05" ixy="5.385E-06" ixz="-5.3212E-07" iyy="5.6429E-05" iyz="7.2049E-06" izz="4.7758E-05" />
    </inertial>
    <visual>
      <origin xyz="0 0 0" rpy="0 0 0" />
      <geometry>
        <mesh filename="package://BrazoparaURDF/meshes/Base_2_link.STL" />
      </geometry>
      <material name="">
        <color rgba="0.79216 0.81961 0.93333 1" />
      </material>
    </visual>
    <collision>
      <origin xyz="0 0 0" rpy="0 0 0" />
      <geometry>
        <mesh filename="package://BrazoparaURDF/meshes/Base_2_link.STL" />
      </geometry>
    </collision>
  </link>
  <joint name="Base_2_joint" type="revolute">
    <origin xyz="0 0 0.056" rpy="1.5708 0 -1.5485" />
    <parent link="base_link" />
    <child link="Base_2_link" />
    <axis xyz="0 1 0" />
    <limit lower="0" upper="0" effort="0" velocity="0" />
  </joint>
  <link name="Eslabon_1_link">
    <inertial>
      <origin xyz="6.31E-07 0.057345 0.003764" rpy="0 0 0" />
      <mass value="0.055061" />
      <inertia ixx="8.4974E-05" ixy="-4.9166E-10" ixz="-7.0163E-11" iyy="7.7321E-06" iyz="-1.4678E-07" izz="8.8974E-05" />
    </inertial>
    <visual>
      <origin xyz="0 0 0" rpy="0 0 0" />
      <geometry>
        <mesh filename="package://BrazoparaURDF/meshes/Eslabon_1_link.STL" />
      </geometry>
      <material name="">
        <color rgba="0 0.2549 0.92157 1" />
      </material>
    </visual>
    <collision>
      <origin xyz="0 0 0" rpy="0 0 0" />
      <geometry>
        <mesh filename="package://BrazoparaURDF/meshes/Eslabon_1_link.STL" />
      </geometry>
    </collision>
  </link>
  <joint name="Eslabon_1_joint" type="revolute">
    <origin xyz="0 0.040276 -0.013918" rpy="1.5708 1.5586 1.5708" />
    <parent link="Base_2_link" />
    <child link="Eslabon_1_link" />
    <axis xyz="0 0 1" />
    <limit lower="0" upper="0" effort="0" velocity="0" />
  </joint>
  <link name="Eslabon_2_link">
    <inertial>
      <origin xyz="4.7632E-05 0.039279 0.01141" rpy="0 0 0" />
      <mass value="0.050182" />
      <inertia ixx="5.4948E-05" ixy="-6.1748E-08" ixz="-2.9949E-10" iyy="8.944E-06" iyz="-2.5004E-07" izz="5.8237E-05" />
    </inertial>
    <visual>
      <origin xyz="0 0 0" rpy="0 0 0" />
      <geometry>
        <mesh filename="package://BrazoparaURDF/meshes/Eslabon_2_link.STL" />
      </geometry>
      <material name="">
        <color rgba="0.79216 0.81961 0.93333 1" />
      </material>
    </visual>
    <collision>
      <origin xyz="0 0 0" rpy="0 0 0" />
      <geometry>
        <mesh filename="package://BrazoparaURDF/meshes/Eslabon_2_link.STL" />
      </geometry>
    </collision>
  </link>
  <joint name="Eslabon_2_joint" type="revolute">
    <origin xyz="0 0.12 0" rpy="-3.1416 0 1.5578" />
    <parent link="Eslabon_1_link" />
    <child link="Eslabon_2_link" />
    <axis xyz="0 0 1" />
    <limit lower="0" upper="0" effort="0" velocity="0" />
  </joint>
  <link name="Eslabon_3_link">
    <inertial>
      <origin xyz="-9.7623E-05 0.0086149 0.021886" rpy="0 0 0" />
      <mass value="0.020316" />
      <inertia ixx="7.2365E-06" ixy="6.558E-08" ixz="1.327E-07" iyy="8.6164E-06" iyz="-1.3265E-06" izz="3.488E-06" />
    </inertial>
    <visual>
      <origin xyz="0 0 0" rpy="0 0 0" />
      <geometry>
        <mesh filename="package://BrazoparaURDF/meshes/Eslabon_3_link.STL" />
      </geometry>
      <material name="">
        <color rgba="0.79216 0.81961 0.93333 1" />
      </material>
    </visual>
    <collision>
      <origin xyz="0 0 0" rpy="0 0 0" />
      <geometry>
        <mesh filename="package://BrazoparaURDF/meshes/Eslabon_3_link.STL" />
      </geometry>
    </collision>
  </link>
  <joint name="Eslabon_3_joint" type="revolute">
    <origin xyz="-0.0050995 0.089782 0.0115" rpy="1.5708 -1.5708 0" />
    <parent link="Eslabon_2_link" />
    <child link="Eslabon_3_link" />
    <axis xyz="0 0 1" />
    <limit lower="0" upper="0" effort="0" velocity="0" />
  </joint>
</robot>

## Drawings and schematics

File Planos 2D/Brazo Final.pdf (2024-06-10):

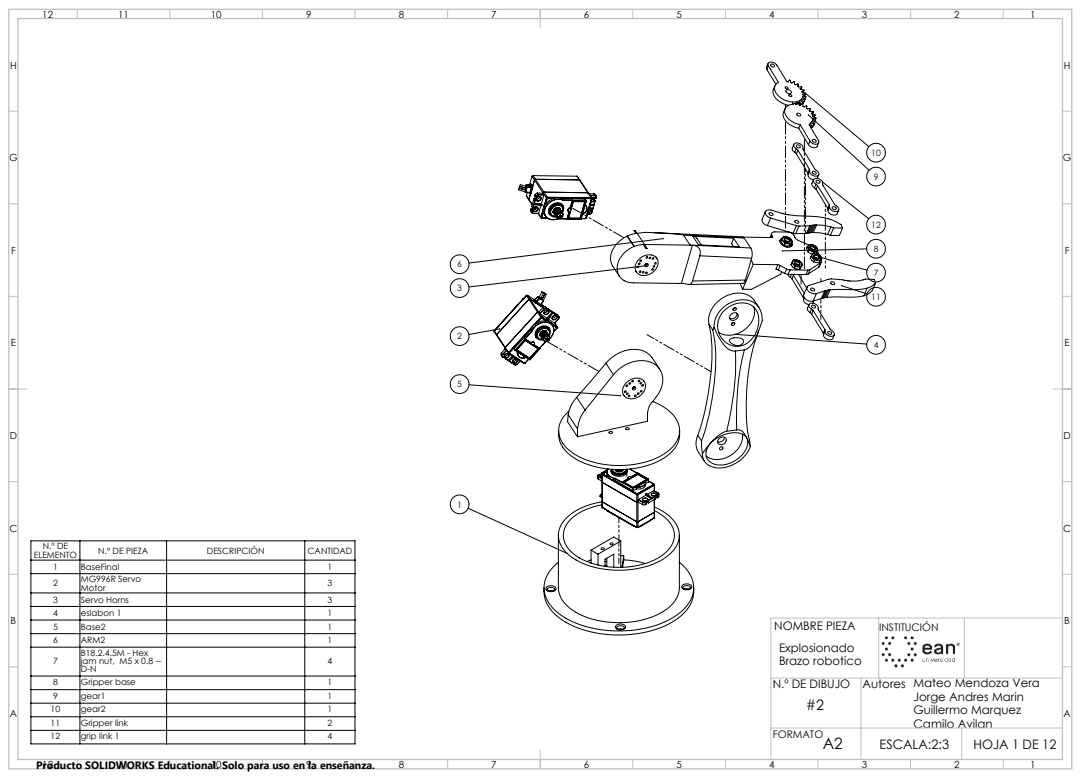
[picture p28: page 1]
MG996R Servo

N.º DE ELEMENTO | N.º DE PIEZA | DESCRIPCIÓN | CANTIDAD
1 | BaseFinal | | 1

3 | Servo Horns | 3
4 | eslabon 1 | 1
5 | Base2 | 1
6 | ARM2 | 1
7 | B18.2.4.5M - Hex jam nut, M5 x 0.8 --D-N | 4

NOMBRE PIEZA Explosionado Brazo robotico | INSTITUCIÓN

8 | Gripper base | 1
9 | gear1 | 1
10 | gear2 | 1
11 | Gripper link | 2
12 | grip link 1 | 4

N.º DE DIBUJO #2 | Autores Mateo Mendoza Vera Jorge Andres Marin Guillermo Marquez Camilo Avilan

FORMATO A2 | ESCALA:2:3 | HOJA 1 DE 12

Producto SOLIDWORKS Educational. Solo para uso en la enseñanza.

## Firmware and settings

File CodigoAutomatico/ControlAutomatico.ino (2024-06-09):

#include <Wire.h>
#include <Adafruit_PWMServoDriver.h>

Adafruit_PWMServoDriver pwm = Adafruit_PWMServoDriver();

// Definición de los límites de pulso para los servos
#define SERVOMIN  150 // Pulso 'mínimo' en microsegundos
#define SERVOMAX  600 // Pulso 'máximo' en microsegundos

// Limites específicos de cada servo
#define SERVO0_MIN 0
#define SERVO0_MAX 180

#define SERVO1_MIN 0
#define SERVO1_MAX 85

#define SERVO2_MIN 0
#define SERVO2_MAX 90

#define SERVO3_MIN 2
#define SERVO3_MAX 90

#define SERVO4_MIN 0
#define SERVO4_MAX 80

// Bandera para controlar la automatización
bool automationActive = false;

void setup() {
  Serial.begin(9600);
  Serial.println("Iniciando PCA9685...");
  
  pwm.begin();
  pwm.setPWMFreq(60);  // Frecuencia PWM estándar para servos
  
  Serial.println("Presiona 'Y' para comenzar la automatización o 'S' para detenerla.");
}

void loop() {
  // Verificar si hay datos disponibles en el puerto serial
  if (Serial.available()) {
    char input = Serial.read();
    
    // Comenzar la automatización si se presiona 'Y'
    if (input == 'Y' || input == 'y') {
      automationActive = true;
      ejecutarSecuencia();
    }
    
    // Detener la automatización si se presiona 'S'
    if (input == 'S' || input == 's') {
      automationActive = false;
      Serial.println("Automatización detenida.");
    }
  }
}

void moverServo(int servo, int angulo) {
  int pulseLength = map(angulo, 0, 180, SERVOMIN, SERVOMAX);
  pwm.setPWM(servo, 0, pulseLength);
  Serial.print("Moviendo servo ");
  Serial.print(servo);
  Serial.print(" a ");
  Serial.print(angulo);
  Serial.println(" grados.");
}

void ejecutarSecuencia() {
  // Posición inicial
  moverServo(0, 90); // Servo 0 a la posición media
  moverServo(1, 0);  // Servo 1 a la posición inicial
  moverServo(2, 0);  // Servo 2 a la posición inicial
  moverServo(3, 2);  // Servo 3 a la posición inicial
  moverServo(4, 80); // Abrir pinza

  delay(1000);

  // Mover brazo a la posición del objeto
  moverServo(0, 90); // Ajustar posición de base
  moverServo(1, 45); // Ajustar posición vertical
  moverServo(2, 45); // Ajustar extensión del brazo
  moverServo(3, 45); // Ajustar inclinación del brazo
  delay(1000); // Esperar para estabilizar

  // Cerrar pinza para agarrar el objeto
  moverServo(4, 0); // Cerrar pinza
  delay(1000); // Esperar para asegurar el agarre

  // Mover brazo a la posición de destino
  moverServo(0, 150); // Ajustar posición de base
  moverServo(1, 20);  // Ajustar posición vertical
  moverServo(2, 20);  // Ajustar extensión del brazo
  moverServo(3, 20);  // Ajustar inclinación del brazo
  delay(1000); // Esperar para estabilizar

  // Abrir pinza para soltar el objeto
  moverServo(4, 80); // Abrir pinza
  delay(1000); // Esperar para asegurar que el objeto se haya soltado

  // Regresar a la posición inicial
  moverServo(0, 90); // Servo 0 a la posición media
  moverServo(1, 0);  // Servo 1 a la posición inicial
  moverServo(2, 0);  // Servo 2 a la posición inicial
  moverServo(3, 2);  // Servo 3 a la posición inicial
  moverServo(4, 80); // Pinza abierta
}

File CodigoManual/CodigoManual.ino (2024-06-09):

#include <Wire.h>
#include <Adafruit_PWMServoDriver.h>

Adafruit_PWMServoDriver pwm = Adafruit_PWMServoDriver();

#define SERVOMIN  150 // Pulso 'mínimo' (valor en microsegundos)
#define SERVOMAX  600 // Pulso 'máximo' (valor en microsegundos)

void setup() {
  Serial.begin(9600);
  Serial.println("Iniciando PCA9685...");
  
  pwm.begin();
  pwm.setPWMFreq(60);  // Frecuencia PWM estándar para servos
  
  // Prueba inicial: Mueve todos los servos a la posición de inicio
  for (int i = 0; i < 5; i++) {
    pwm.setPWM(i, 0, SERVOMIN);
  }

  Serial.println("Listo para recibir comandos.");
}

void loop() {
  if (Serial.available()) {
    String command = Serial.readStringUntil('\n');
    processCommand(command);
  }
}

void processCommand(String command) {
  if (command.length() < 2) {
    Serial.println("Comando demasiado corto. Use formato <servo><ángulo> (ej. 2150 para mover el servo 2 a 150 grados).");
    return;
  }

  int servoIndex = command.charAt(0) - '0';
  int angle = command.substring(1).toInt();

  if (servoIndex >= 0 && servoIndex < 5 && angle >= 0 && angle <= 180) {
    int pulseLength = map(angle, 0, 180, SERVOMIN, SERVOMAX);
    pwm.setPWM(servoIndex, 0, pulseLength);
    Serial.print("Servo ");
    Serial.print(servoIndex);
    Serial.print(" movido a ");
    Serial.print(angle);
    Serial.println(" grados.");
  } else {
    Serial.println("Comando inválido. Use formato <servo><ángulo> (ej. 2150 para mover el servo 2 a 150 grados).");
  }
}

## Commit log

2024-06-09 Se agregaron los codigos manual y automatico y los diseños 3D
    [ARM2.SLDPRT, Base2.SLDPRT, BaseFinal.SLDPRT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]
2024-06-09 se agregan los codigos de cinematica inversa
2024-06-09 se agrega el codigo de la cinematica inversa en formato .py
2024-06-09 se implementa solo el archivo en formato .ipynb
2024-06-10 se agregan los archivos .urdf para el entorno de simulacion en ros2
    [Base_2_link.STL, BrazoparaURDF.csv, BrazoparaURDF.urdf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]
2024-06-10 se agrega el codigo de la cinematica inversa
2024-06-10 se agrega el archivo de la cinematica inversa
2024-06-10 se agregan los planos 2D del Brazo Robotico
    [ARM2.SLDDRW, Base2.SLDDRW, BaseFinal.SLDDRW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]
2024-06-10 se agregan los archivos del diseño 3D
    [ARM2.SLDPRT, Base2.SLDPRT, BaseFinal.SLDPRT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]
2024-06-10 se agrega el plano 2D del explosionado del brazo
2024-06-10 se agrega el informe del proyecto
